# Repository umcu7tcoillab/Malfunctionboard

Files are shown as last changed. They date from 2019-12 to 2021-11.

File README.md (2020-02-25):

# Malfunctionboard

## About us
This design has been made by the coil-lab of the High Field MRI Group of the UMC Utrecht in the Netherlands, where we make hardware to support our researchers. We are part of a research group which means we feel the need to open up some of our designs to whomever can make use of it, to further the research of MRI applications.

## The design
This project contains a Malfunctionboard made for our 7T Philips Achieva MRI system. It has been tested inside the magnetic field of the 7T MRI. 

The Malfunctionboard is used to check the state of the PIN-diodes of the attachted coil. Between 1 and 3 diodes (0.4-2.6V) passes the test, otherwise the malfunctionline will not be pulled high.

The design and subsequent drawing has been done in Kicad 5.1.5.

## Download
Gerber and BOM production files for the latest _field tested_ version of the PCB can be found in the 'Releases' page, or by following [this link](https://github.com/umcu7tcoillab/Malfunctionboard/releases/latest). 
You can also make your own production files by downloading the Kicad project and generating them, but these are not guaranteed to have been field tested.

## Images
**3D Image**
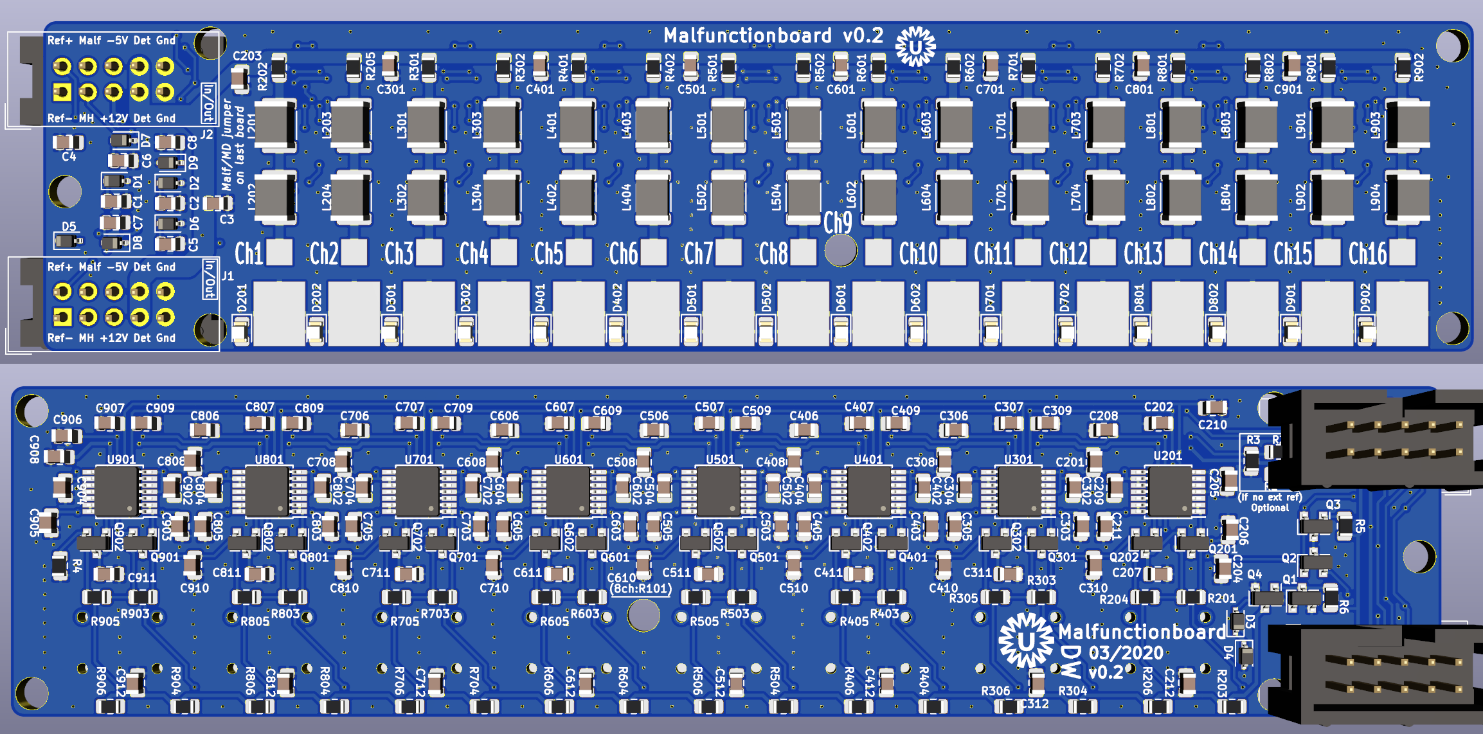
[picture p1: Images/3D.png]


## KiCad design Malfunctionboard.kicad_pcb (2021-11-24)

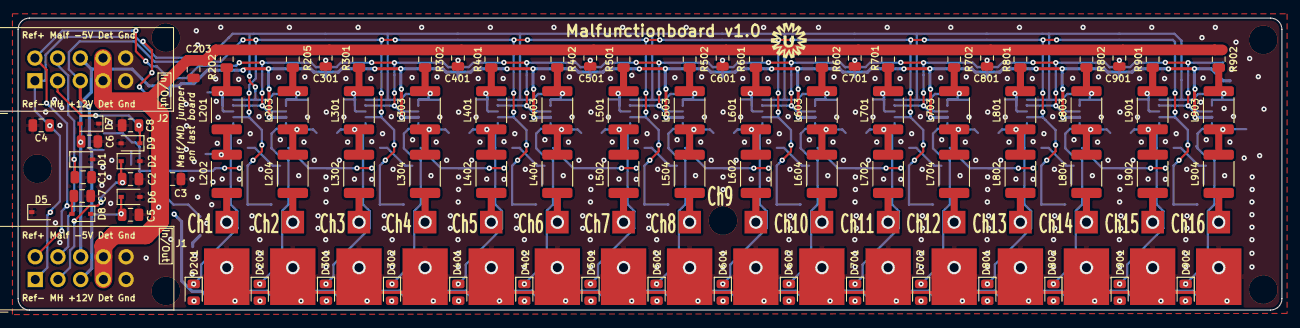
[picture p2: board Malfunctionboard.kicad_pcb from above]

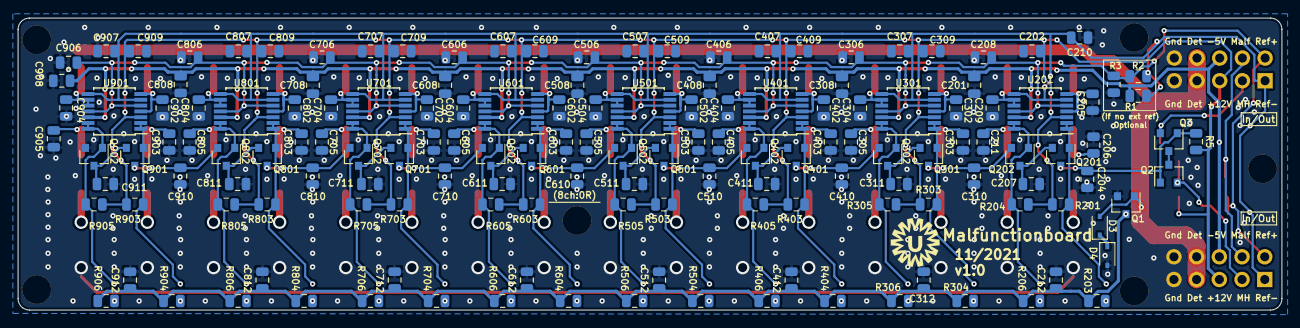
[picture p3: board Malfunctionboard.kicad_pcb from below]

Board: 2 copper layers, 141.4 x 32.7 mm, 265 parts (154 on the bottom side), 108 nets.

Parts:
C1, C2, C3, C4, C7, C8, C203, C204, C205, C206, C207, C208, C209, C210, C211, C301, C302, C303, C304, C305, C306, C307, C310, C311, C401, C402, C403, C404, C405, C406, C407, C410, C411, C501, C502, C503, C504, C505, C506, C507, C510, C511, C601, C602, C603, C604, C605, C606, C607, C610, C611, C701, C702, C703, C704, C705, C706, C707, C710, C711, C801, C802, C803, C804, C805, C806, C807, C810, C811, C901, C902, C903, C904, C905, C906, C907, C910, C911: 470pF; C_0805_2012Metric
C5, C6, C201, C202, C212, C308, C309, C312, C408, C409, C412, C508, C509, C512, C608, C609, C612, C708, C709, C712, C808, C809, C812, C908, C909, C912: 10n; C_0805_2012Metric
D1, D2, D6, D9: 15V; D_SOD-323
D3, D5, D7, D8: 5.4V; D_SOD-323
D4: 12V; D_SOD-323
D201, D202, D301, D302, D401, D402, D501, D502, D601, D602, D701, D702, D801, D802, D901, D902: LED; LED_0805_2012Metric
H1, H3, H4, H5, H6, H7: MH_Pad; MountingHole_3.2mm_M3_plated
J1, J2: In/out; IDC-Header_2x05_P2.54mm_Vertical
J201, J202, J301, J302, J401, J402, J501, J502, J601, J602, J701, J702, J801, J802, J901, J902: Conn_Coaxial; Solder straight thin coax cable
L201, L202, L203, L204, L301, L302, L303, L304, L401, L402, L403, L404, L501, L502, L503, L504, L601, L602, L603, L604, L701, L702, L703, L704, L801, L802, L803, L804, L901, L902, L903, L904: 1u; L_1812_4532Metric
Q1, Q2, Q3: RSC002P03T316; SOT-23
Q201, Q202, Q301, Q302, Q401, Q402, Q501, Q502, Q601, Q602, Q701, Q702, Q801, Q802, Q901, Q902: NTR5103NT1G; SOT-23
R1: R_Ref-; R_0805_2012Metric
R2: R_Ref; R_0805_2012Metric
R3: R_Ref+; R_0805_2012Metric
R5: 1k; R_0805_2012Metric
R201, R204, R303, R305, R403, R405, R503, R505, R603, R605, R703, R705, R803, R805, R903, R905: 100k; R_0805_2012Metric
R202, R205, R301, R302, R401, R402, R501, R502, R601, R602, R701, R702, R801, R802, R901, R902: 150R; R_0805_2012Metric
R203, R206, R304, R306, R404, R406, R504, R506, R604, R606, R704, R706, R804, R806, R904, R906: 10k; R_0805_2012Metric
SYM1: SYM_Magnet_Small; UMC_logo_small
U201, U301, U401, U501, U601, U701, U801, U901: LM339PW; TSSOP-14_4.4x5mm_P0.65mm

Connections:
+12V: C5.1, C202.2, C309.2, C409.2, C509.2, C609.2, C709.2, C809.2, C909.2, D6.1, J1.5, J2.5, R5.1, R201.1, R204.1, R303.1, R305.1, R403.1, R405.1, R503.1, R505.1, R603.1, R605.1, R703.1, R705.1, R803.1, R805.1, R903.1, R905.1, U201.3, U301.3, U401.3, U501.3, U601.3, U701.3, U801.3, U901.3
-5V: C6.1, C201.2, C308.2, C408.2, C508.2, C608.2, C708.2, C808.2, C908.2, D7.2, J1.6, J2.6, R1.1, U201.12, U301.12, U401.12, U501.12, U601.12, U701.12, U801.12, U901.12
/MH_1: C2.2, D2.1, J1.3, Q2.2
/MH_2: C8.2, D9.1, J2.3, Q3.2
/Malf: C1.2, D1.1, J1.4, J2.4
/Ref+: C7.2, C208.2, C306.2, C406.2, C506.2, C606.2, C706.2, C806.2, C906.2, D8.2, J1.2, J2.2, R2.2, R3.1, U201.5, U201.11, U301.5, U301.11, U401.5, U401.11, U501.5, U501.11, U601.5, U601.11, U701.5, U701.11, U801.5, U801.11, U901.5, U901.11
/Ref-: C4.2, C210.2, C307.2, C407.2, C507.2, C607.2, C707.2, C807.2, C907.2, D5.2, J1.1, J2.1, R1.2, R2.1, U201.6, U201.8, U301.6, U301.8, U401.6, U401.8, U501.6, U501.8, U601.6, U601.8, U701.6, U701.8, U801.6, U801.8, U901.6, U901.8
/V_detune: C3.2, C203.2, C301.2, C401.2, C501.2, C601.2, C701.2, C801.2, C901.2, D3.2, J1.7, J1.8, J2.7, J2.8, Q1.1, R202.1, R205.1, R301.1, R302.1, R401.1, R402.1, R501.1, R502.1, R601.1, R602.1, R701.1, R702.1, R801.1, R802.1, R901.1, R902.1
/sheet5DD8DCB3/LED_GND: C212.1, C312.1, C412.1, C512.1, C612.1, C712.1, C812.1, C912.1, Q1.3, R203.2, R206.2, R304.2, R306.2, R404.2, R406.2, R504.2, R506.2, R604.2, R606.2, R704.2, R706.2, R804.2, R806.2, R904.2, R906.2
/sheet5DD8DCB3/Malf: C310.2, Q202.2, Q301.3
/sheet5DD8DCB3/Malf_in: C204.2, Q2.1, Q3.1, Q201.3, R5.2
/sheet5DE59C6C/Malf: C410.2, Q302.2, Q401.3
/sheet5DF0CFC9/Malf: C510.2, Q402.2, Q501.3
/sheet5DF0CFCA/Malf: C610.2, Q502.2, Q601.3
/sheet5DF270F0/Malf: C710.2, Q602.2, Q701.3
/sheet5DF270F1/Malf: C810.2, Q702.2, Q801.3
/sheet5DF3552B/Malf: C910.2, Q802.2, Q901.3
GND: C1.1, C2.1, C3.1, C4.1, C5.2, C6.2, C7.1, C8.1, C201.1, C202.1, C203.1, C204.1, C205.1, C206.1, C207.2, C208.1, C209.1, C210.1, C211.1, C212.2, C301.1, C302.1, C303.1, C304.1, C305.1, C306.1, C307.1, C308.1, C309.1, C310.1, C311.2, C312.2, C401.1, C402.1, C403.1, C404.1, C405.1, C406.1, C407.1, C408.1, C409.1, C410.1, C411.2, C412.2, C501.1, C502.1, C503.1, C504.1, C505.1, C506.1, C507.1, C508.1, C509.1, C510.1, C511.2, C512.2, C601.1, C602.1, C603.1, C604.1, C605.1, C606.1, C607.1, C608.1, C609.1, C610.1, C611.2, C612.2, C701.1, C702.1, C703.1, C704.1, C705.1, C706.1, C707.1, C708.1, C709.1, C710.1, C711.2, C712.2, C801.1, C802.1, C803.1, C804.1, C805.1, C806.1, C807.1, C808.1, C809.1, C810.1, C811.2, C812.2, C901.1, C902.1, C903.1, C904.1, C905.1, C906.1, C907.1, C908.1, C909.1, C910.1, C911.2, C912.2, D1.2, D2.2, D4.2, D5.1, D6.2, D7.1, D8.1, D9.2, H1.1, H3.1, H4.1, H5.1, H6.1, H7.1, J1.9, J1.10, J2.9, J2.10, J201.2, J202.2, J301.2, J302.2, J401.2, J402.2, J501.2, J502.2, J601.2, J602.2, J701.2, J702.2, J801.2, J802.2, J901.2, J902.2, Q1.2, Q902.2, R3.2
unnamed: C205.2, L201.2, R202.2, U201.4, U201.7
unnamed: C206.2, L201.1, L202.2
unnamed: C207.1, Q201.2, Q202.3
unnamed: C209.2, L203.2, R205.2, U201.9, U201.10
unnamed: C211.2, L203.1, L204.2
unnamed: C302.2, L301.2, R301.2, U301.4, U301.7
unnamed: C303.2, L301.1, L302.2
unnamed: C304.2, L303.2, R302.2, U301.9, U301.10
unnamed: C305.2, L303.1, L304.2
unnamed: C311.1, Q301.2, Q302.3
unnamed: C402.2, L401.2, R401.2, U401.4, U401.7
unnamed: C403.2, L401.1, L402.2
unnamed: C404.2, L403.2, R402.2, U401.9, U401.10
unnamed: C405.2, L403.1, L404.2
unnamed: C411.1, Q401.2, Q402.3
unnamed: C502.2, L501.2, R501.2, U501.4, U501.7
unnamed: C503.2, L501.1, L502.2
unnamed: C504.2, L503.2, R502.2, U501.9, U501.10
unnamed: C505.2, L503.1, L504.2
unnamed: C511.1, Q501.2, Q502.3
unnamed: C602.2, L601.2, R601.2, U601.4, U601.7
unnamed: C603.2, L601.1, L602.2
unnamed: C604.2, L603.2, R602.2, U601.9, U601.10
unnamed: C605.2, L603.1, L604.2
unnamed: C611.1, Q601.2, Q602.3
unnamed: C702.2, L701.2, R701.2, U701.4, U701.7
unnamed: C703.2, L701.1, L702.2
unnamed: C704.2, L703.2, R702.2, U701.9, U701.10
unnamed: C705.2, L703.1, L704.2
unnamed: C711.1, Q701.2, Q702.3
unnamed: C802.2, L801.2, R801.2, U801.4, U801.7
unnamed: C803.2, L801.1, L802.2
unnamed: C804.2, L803.2, R802.2, U801.9, U801.10
unnamed: C805.2, L803.1, L804.2
unnamed: C811.1, Q801.2, Q802.3
unnamed: C902.2, L901.2, R901.2, U901.4, U901.7
unnamed: C903.2, L901.1, L902.2
unnamed: C904.2, L903.2, R902.2, U901.9, U901.10
unnamed: C905.2, L903.1, L904.2
unnamed: C911.1, Q901.2, Q902.3
unnamed: D3.1, D4.1
unnamed: D201.1, Q201.1, R201.2, U201.1, U201.2
unnamed: D201.2, R203.1
unnamed: D202.1, Q202.1, R204.2, U201.13, U201.14
unnamed: D202.2, R206.1
unnamed: D301.1, Q301.1, R303.2, U301.1, U301.2
unnamed: D301.2, R304.1
unnamed: D302.1, Q302.1, R305.2, U301.13, U301.14
unnamed: D302.2, R306.1
unnamed: D401.1, Q401.1, R403.2, U401.1, U401.2
unnamed: D401.2, R404.1
unnamed: D402.1, Q402.1, R405.2, U401.13, U401.14
unnamed: D402.2, R406.1
unnamed: D501.1, Q501.1, R503.2, U501.1, U501.2
unnamed: D501.2, R504.1
unnamed: D502.1, Q502.1, R505.2, U501.13, U501.14
unnamed: D502.2, R506.1
unnamed: D601.1, Q601.1, R603.2, U601.1, U601.2
unnamed: D601.2, R604.1
unnamed: D602.1, Q602.1, R605.2, U601.13, U601.14
unnamed: D602.2, R606.1
unnamed: D701.1, Q701.1, R703.2, U701.1, U701.2
unnamed: D701.2, R704.1
unnamed: D702.1, Q702.1, R705.2, U701.13, U701.14
unnamed: D702.2, R706.1
unnamed: D801.1, Q801.1, R803.2, U801.1, U801.2
unnamed: D801.2, R804.1
unnamed: D802.1, Q802.1, R805.2, U801.13, U801.14
unnamed: D802.2, R806.1
unnamed: D901.1, Q901.1, R903.2, U901.1, U901.2
unnamed: D901.2, R904.1
unnamed: D902.1, Q902.1, R905.2, U901.13, U901.14
unnamed: D902.2, R906.1
unnamed: J201.1, L202.1
unnamed: J202.1, L204.1
unnamed: J301.1, L302.1
unnamed: J302.1, L304.1
unnamed: J401.1, L402.1
unnamed: J402.1, L404.1
unnamed: J501.1, L502.1
unnamed: J502.1, L504.1
unnamed: J601.1, L602.1
unnamed: J602.1, L604.1
unnamed: J701.1, L702.1
unnamed: J702.1, L704.1
unnamed: J801.1, L802.1
unnamed: J802.1, L804.1
unnamed: J901.1, L902.1
unnamed: J902.1, L904.1
unnamed: Q2.3, Q3.3

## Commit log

2019-11-21 Changed: more robust malfunction check
    [simuation.sch, simuation2.sch]
2019-11-22 Finished main design
    [1ch_malf.sch, Malfunctionboard UMCU.sch, simuation.sch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]
2019-11-22 Changed: design to accomodate quad comparator package. Added: all labels for the connectors
    [1ch_malf.sch, Malfunctionboard UMCU.kicad_pcb, Malfunctionboard UMCU.sch]
2019-11-22 Made first pcb sketch, but is too wide
    [Malfunctionboard UMCU.kicad_pcb]
2019-11-23 Finished main pcb design. Todo: move decouple C's to backside, move logic at connectors to back, better mounting hole position
    [1ch_malf.sch, Malfunctionboard UMCU.kicad_pcb, Malfunctionboard UMCU.sch]
2019-11-24 Finished v0.1
    [1ch_malf.sch, Malfunctionboard UMCU.kicad_pcb, Malfunctionboard UMCU.sch]
2019-11-25 Changed: started changing circuit between connectors
    [1ch_malf.sch, Malfunctionboard UMCU.kicad_pcb, Malfunctionboard UMCU.sch]
2019-11-25 changed: Added extra protection C's to v0.1
    [Malfunctionboard UMCU.kicad_pcb, Malfunctionboard UMCU.sch]
2019-11-27 Ready for ordering. Changed: some overlapping via's, moved mounting holes slightly and made them plated.
    [Malfunctionboard UMCU.kicad_pcb, Malfunctionboard UMCU.sch]
2019-12-11 Changed: small changes
    [1ch_malf.sch, Malfunctionboard UMCU.kicad_pcb, Malfunctionboard UMCU.sch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]
2019-12-19 Changed: different annotations, small changes
    [1ch_malf.sch, Malfunctionboard UMCU.sch, simuation.sch]
2020-02-25 Added: Through holes in the coaxial pads, for use as interfacebox module; README, LICENSE.
    [1ch_malf.sch, Malfunctionboard.kicad_pcb, Malfunctionboard.sch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]
2020-02-26 Changed: Removed unnecessary references in file
    [1ch_malf.sch, Malfunctionboard.sch]
2020-02-26 Removed: unnecessary file
    [Malfunctionboard UMCU.kicad_pcb]
2020-03-12 Fixed: wrong pin layout for comparator
    [1ch_malf.sch, Malfunctionboard.kicad_pcb, Malfunctionboard.sch]
2020-03-18 Changed: Adjusted the in/out connectors for new driverboard (v0.3)
    [1ch_malf.sch, Malfunctionboard.kicad_pcb, Malfunctionboard.sch]
2020-03-18 Updated: date & version
    [1ch_malf.sch, Malfunctionboard.sch]
2020-04-10 Changed: version number. Added: one missing track on comparator. Removed: resistor on internal malfunction
    [1ch_malf.sch, Malfunctionboard.kicad_pcb, Malfunctionboard.sch]
2020-04-24 Changed: fixed mistake in turning off LED's during +12v on detune.
    [1ch_malf.sch, Malfunctionboard.kicad_pcb, Malfunctionboard.sch]
2021-11-24 Changed: resistor and zener diode values.
    [1ch_malf.sch, Malfunctionboard.kicad_pcb, Malfunctionboard.sch]
2021-11-24 Updated to v1.0
    [1ch_malf.sch, Malfunctionboard.kicad_pcb, Malfunctionboard.sch]
2021-11-24 Updated version date
    [Malfunctionboard.kicad_pcb]
